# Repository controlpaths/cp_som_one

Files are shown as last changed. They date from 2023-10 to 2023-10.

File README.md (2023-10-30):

# CP SOM ONE

The CP SOM ONE is a Open Source System-On-Module that features an FPGA Artix7 from AMD. 

## Images

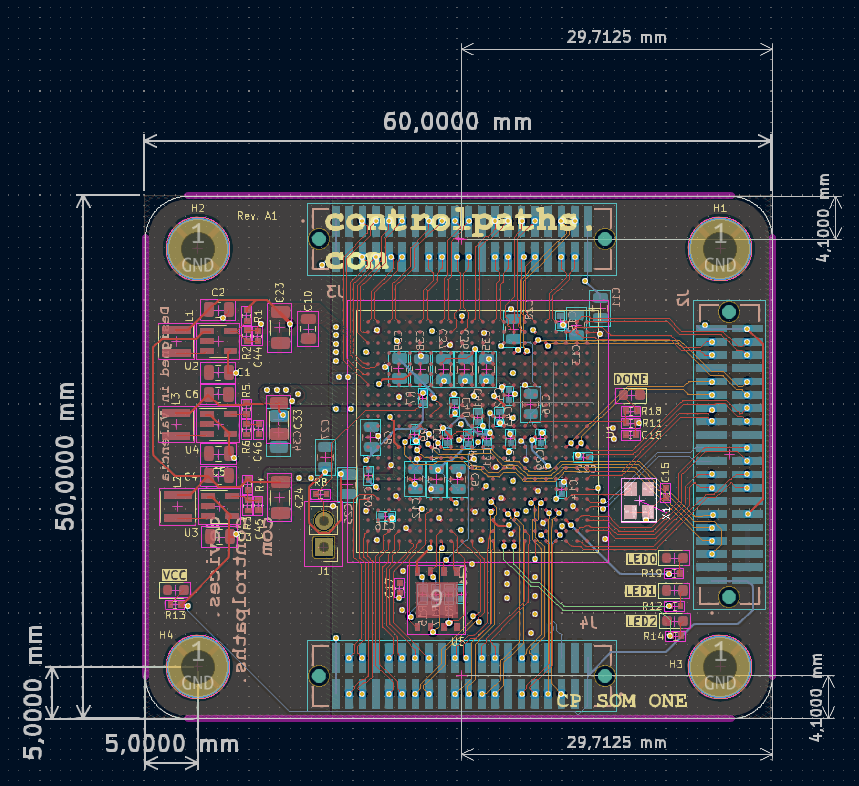
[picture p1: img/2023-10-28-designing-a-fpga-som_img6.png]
 

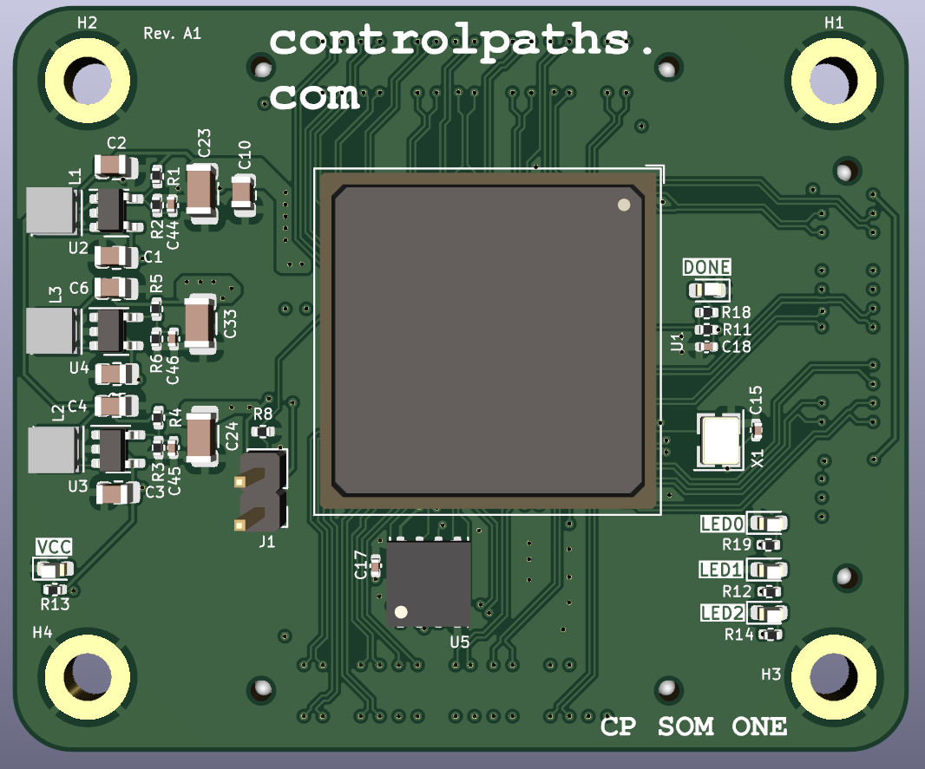
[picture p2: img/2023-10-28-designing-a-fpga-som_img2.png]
 

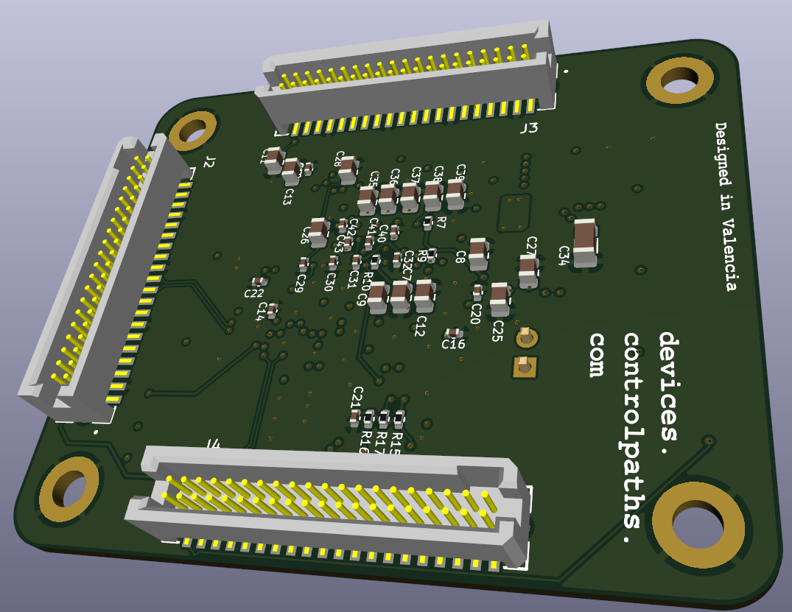
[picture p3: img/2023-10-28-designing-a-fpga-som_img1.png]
 

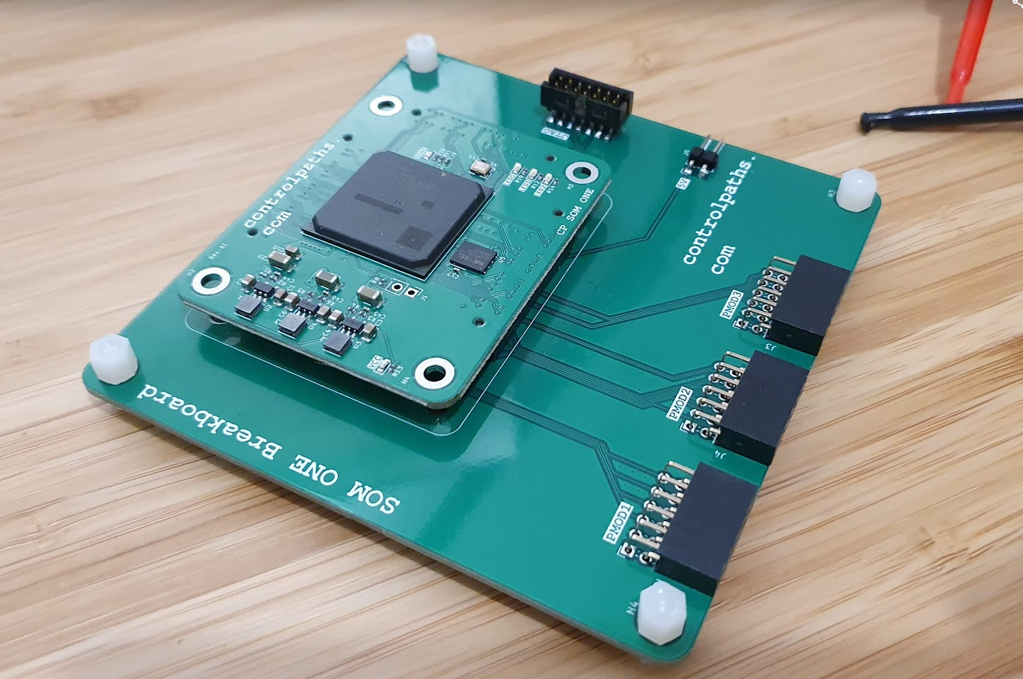
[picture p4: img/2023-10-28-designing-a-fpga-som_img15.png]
 

**More information in [controlpaths.com](https://www.controlpaths.com/2023/10/28/designing-a-fpga-som/)**

## Get yours

The CP SOM ONE is open source and all the files are shared. If you want to build your own, you can to go to the [JLCPCB](https://jlcpcb.com/?from=controlpaths) website, click on Order Now, and upload a zip file with all the fabrication files.

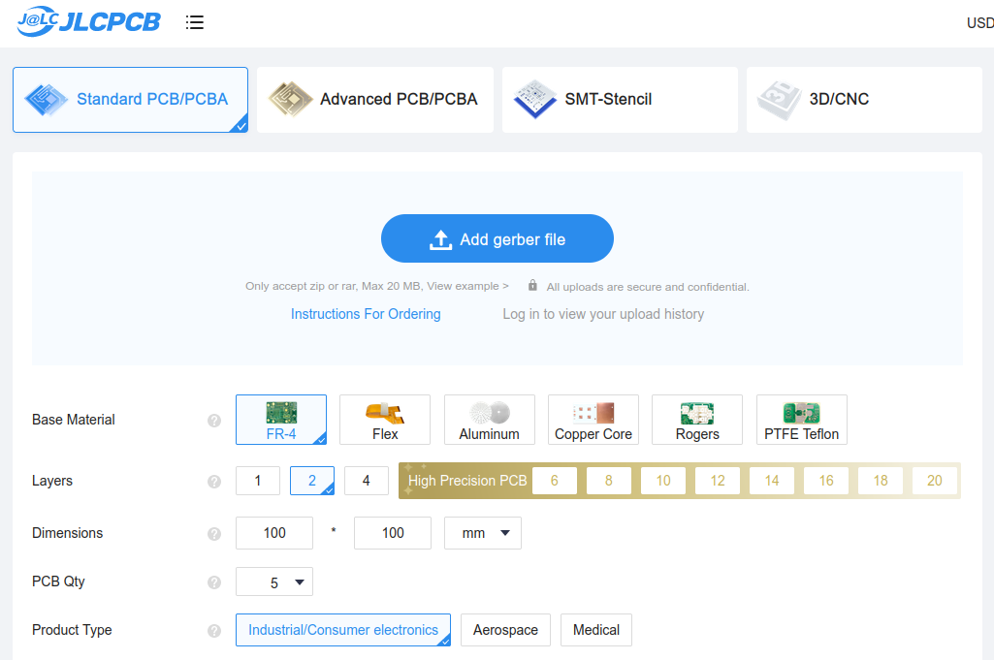
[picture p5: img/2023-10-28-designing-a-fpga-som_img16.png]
 

Then, you have to configure some aspects of the board. For this SOM, I just changed the Surface Finish to LeadFree HASL. Also, you can customize the color of your board.

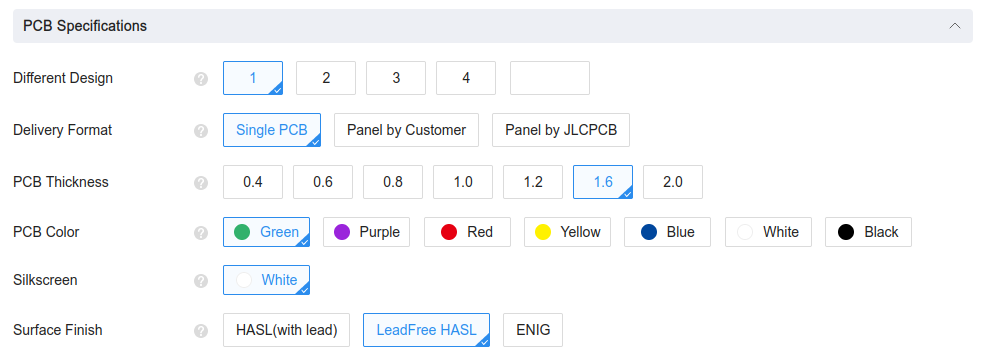
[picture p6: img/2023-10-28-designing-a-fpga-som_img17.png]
 

When the PCB service options are ready, then you have to select the PCB Assembly process. here we have to set whether the components are on one or both sides of the board, and the quantity we need. 

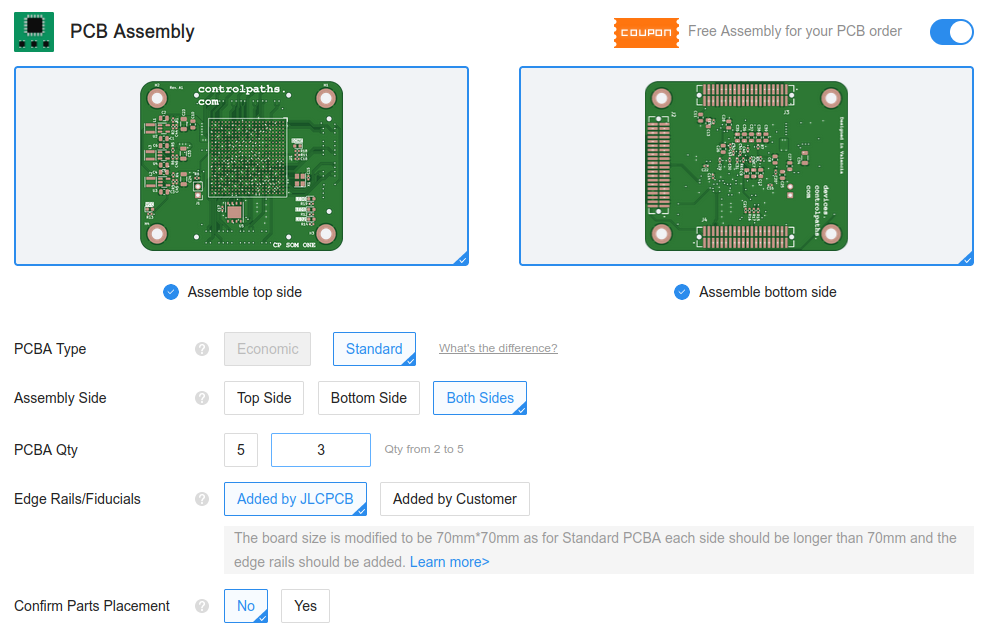
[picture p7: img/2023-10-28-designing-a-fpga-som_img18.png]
 

Then, when we confirm the board, the web application will ask us for two files, the position file for the components, and the bill of materials. Both files are generated in KiCad and are available in the GitHub repository.

Finally, you have to complete the order and two weeks later, the board will be in your house.

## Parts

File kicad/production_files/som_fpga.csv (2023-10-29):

# | Reference | Qty | Value | Footprint | DNP | JLCPCB
1 | C1, C3, C5, C7, C8, C9, C10, C11, C12, C13, C25, C26, C27, C28, C35, C36, C37, C38, C39 | 19 | 4u7 | Capacitor_SMD:C_0805_2012Metric |  | C162420
2 | C2, C4, C6 | 3 | 10u | Capacitor_SMD:C_0805_2012Metric |  | C105505
3 | C14, C15, C16, C17, C18, C19, C20, C21, C22, C29, C30, C31, C32, C40, C41, C42, C43, C44, C45, C46 | 20 | 0.47u | Capacitor_SMD:C_0402_1005Metric |  | C106255
4 | C23, C24 | 2 | 47u | Capacitor_SMD:C_1206_3216Metric |  | C385907
5 | C33, C34 | 2 | 100u | Capacitor_SMD:C_1206_3216Metric |  | C268006
6 | D1 | 1 | DONE | LED_SMD:LED_0603_1608Metric |  | C89814
7 | D2 | 1 | VCC | LED_SMD:LED_0603_1608Metric |  | C601673
8 | D3, D4, D5 | 3 | USER_LED | LED_SMD:LED_0603_1608Metric |  | C40378
9 | L1, L2, L3 | 3 | 2u2 | inductors:IND_LQH3NPN2R2MJRL |  | C341775
10 | R1 | 1 | 100k | Resistor_SMD:R_0402_1005Metric |  | C131362
11 | R2, R5 | 2 | 22k | Resistor_SMD:R_0402_1005Metric |  | C409681
12 | R3 | 1 | 120k | Resistor_SMD:R_0402_1005Metric |  | C323683
13 | R4 | 1 | 240k | Resistor_SMD:R_0402_1005Metric |  | C323663
14 | R6 | 1 | 33k | Resistor_SMD:R_0402_1005Metric |  | C416388
15 | R7, R8, R9, R10, R15, R16, R17 | 7 | 4k7 | Resistor_SMD:R_0402_1005Metric |  | C3017492
16 | R11 | 1 | 330 | Resistor_SMD:R_0402_1005Metric |  | C881192
17 | R12, R13, R14, R19 | 4 | 10k | Resistor_SMD:R_0402_1005Metric |  | C328298
18 | R18 | 1 | 100 | Resistor_SMD:R_0402_1005Metric |  | C471762
19 | U1 | 1 | XC7A75T-FGG484 | Package_BGA:FB-BGA-484_23.0x23.0mm_Layout22x22_P1.0mm |  | C396343
20 | U2 | 1 | TLV62565DBVR | Package_TO_SOT_SMD:SOT-23-5 |  | C87122
21 | U3, U4 | 2 | TLV62565DBVR | Package_TO_SOT_SMD:SOT-23-5 |  | C23902
22 | U5 | 1 | MX25L12833F | Package_SON:WSON-8-1EP_6x5mm_P1.27mm_EP3.4x4mm |  | C2802709
23 | X1 | 1 | SG-8018CE | Crystal:Crystal_SMD_3225-4Pin_3.2x2.5mm |  | C390488

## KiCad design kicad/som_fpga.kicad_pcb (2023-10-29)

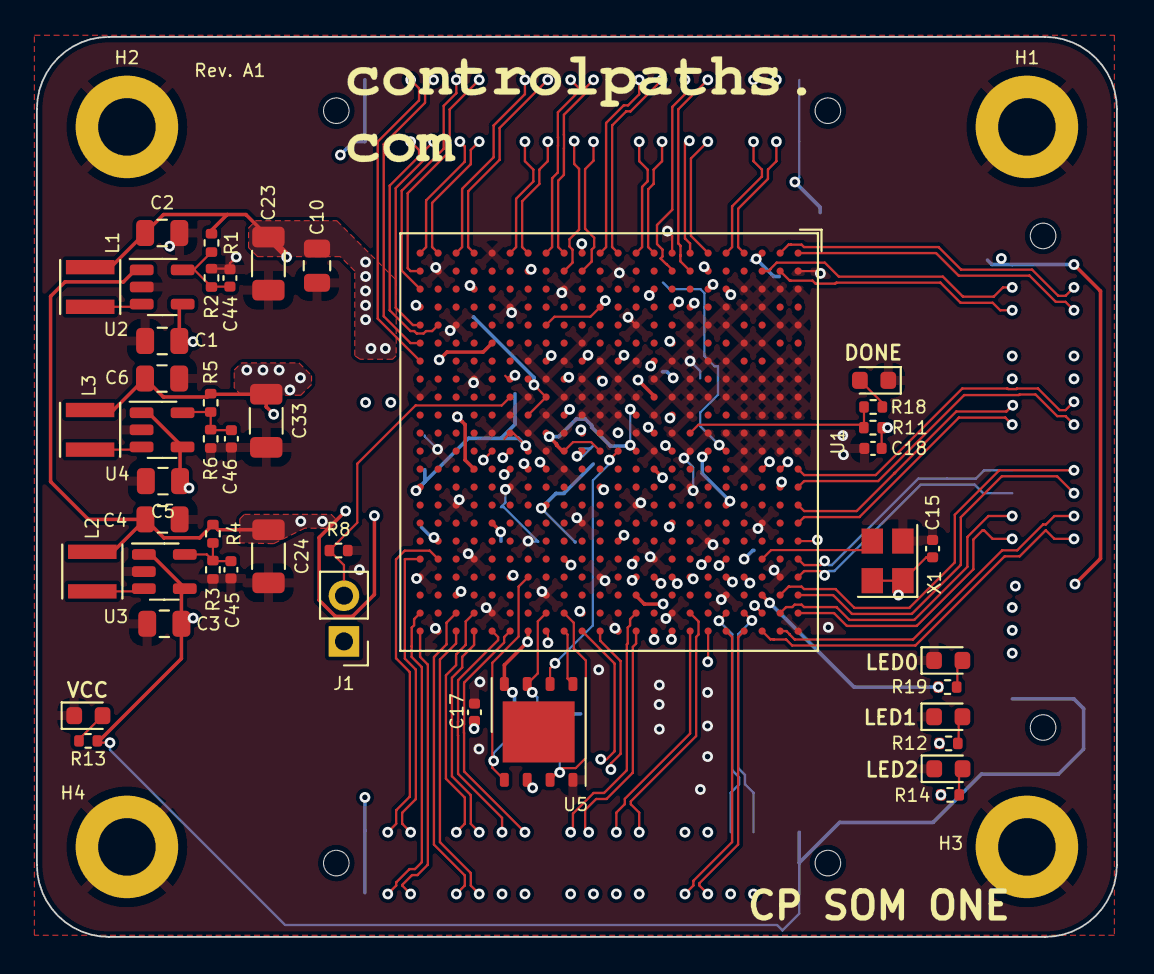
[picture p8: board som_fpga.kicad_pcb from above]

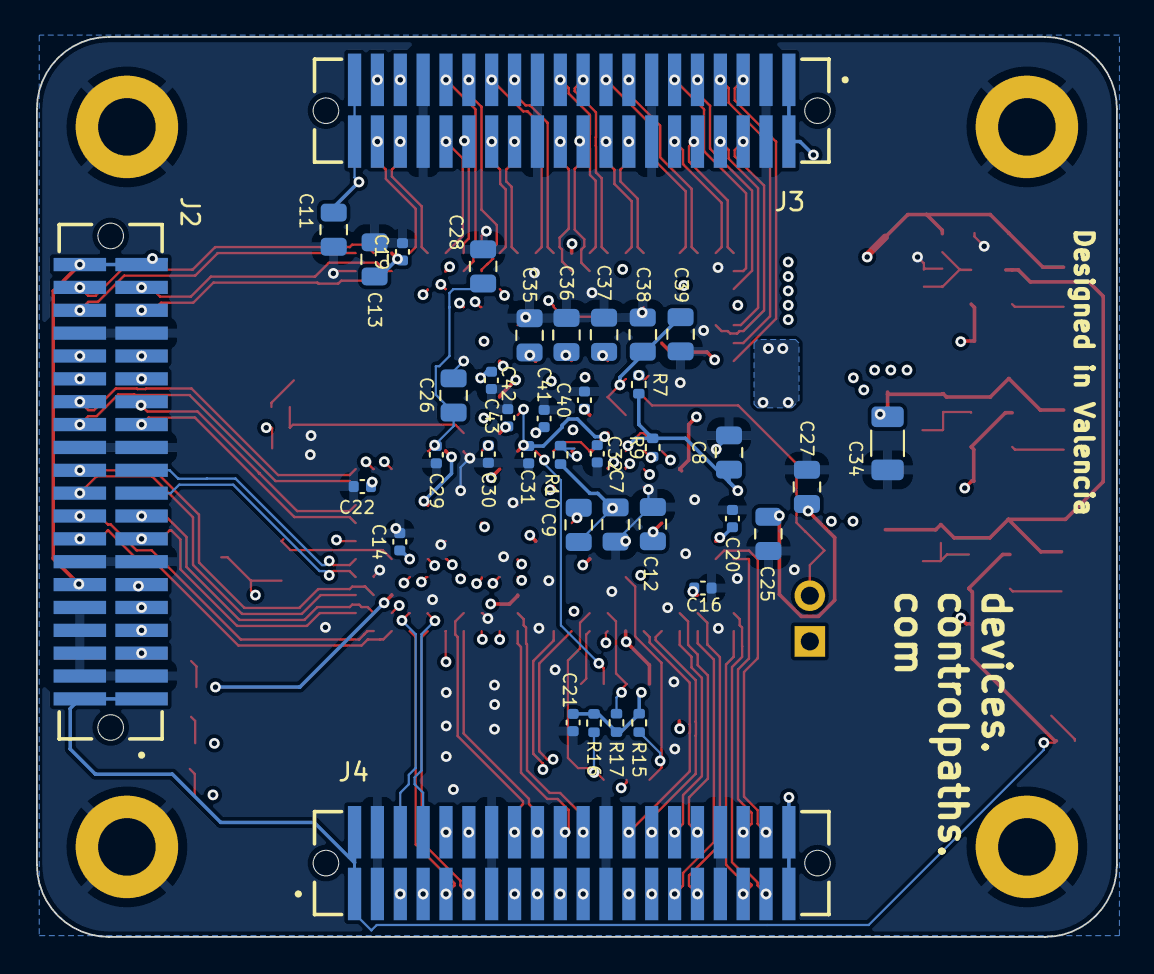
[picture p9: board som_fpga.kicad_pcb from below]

Board: 4 copper layers, 60.0 x 50.0 mm, 88 parts (39 on the bottom side), 111 nets.

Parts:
C1, C3, C5, C7, C8, C9, C10, C11, C12, C13, C25, C26, C27, C28, C35, C36, C37, C38, C39: 4u7; C_0805_2012Metric
C2, C4, C6: 10u; C_0805_2012Metric
C14, C15, C16, C17, C18, C19, C20, C21, C22, C29, C30, C31, C32, C40, C41, C42, C43, C44, C45, C46: 0.47u; C_0402_1005Metric
C23, C24: 47u; C_1206_3216Metric
C33, C34: 100u; C_1206_3216Metric
D1: DONE; LED_0603_1608Metric
D2: VCC; LED_0603_1608Metric
D3, D4, D5: USER_LED; LED_0603_1608Metric
H1, H2, H3, H4: MountingHole_Pad; MountingHole_3.2mm_M3_ISO7380_Pad
J1: Conn_01x02_Pin; PinHeader_1x02_P2.54mm_Vertical
J2, J3, J4: Conn_02x20_Odd_Even; SAMTEC_TFM-120-02-S-D-A
L1, L2, L3: 2u2; IND_LQH3NPN2R2MJRL
R1: 100k; R_0402_1005Metric
R2, R5: 22k; R_0402_1005Metric
R3: 120k; R_0402_1005Metric
R4: 240k; R_0402_1005Metric
R6: 33k; R_0402_1005Metric
R7, R8, R9, R10, R15, R16, R17: 4k7; R_0402_1005Metric
R11: 330; R_0402_1005Metric
R12, R13, R14, R19: 10k; R_0402_1005Metric
R18: 100; R_0402_1005Metric
U1: XC7A35T-FGG484; FB-BGA-484_23.0x23.0mm_Layout22x22_P1.0mm
U2, U3, U4: TLV62565DBVR; SOT-23-5
U5: MX25L12833F; WSON-8-1EP_6x5mm_P1.27mm_EP3.4x4mm
U6: cp_logo25mm; logo25mm
X1: SG-8018CE; Crystal_SMD_3225-4Pin_3.2x2.5mm

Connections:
+1V0: C6.1, C33.1, C34.1, C35.1, C36.1, C37.1, C38.1, C39.1, C40.1, C41.1, C42.1, C43.1, L3.2, R5.1, U1.H8 (VCCINT), U1.H10 (VCCINT), U1.J7 (VCCINT), U1.J9 (VCCINT), U1.J11 (VCCBRAM), U1.K8 (VCCINT), U1.L7 (VCCINT), U1.L11 (VCCBRAM), U1.M8 (VCCINT), U1.N7 (VCCINT), U1.N11 (VCCBRAM), U1.P8 (VCCINT), U1.P10 (VCCINT), U1.R7 (VCCINT), U1.R9 (VCCINT), U1.T8 (VCCINT), U1.T10 (VCCINT)
+1V8: C4.1, C24.1, C25.1, C26.1, C27.1, C28.1, C29.1, C30.1, C31.1, C32.1, L2.2, R4.1, U1.E12 (VCCBATT_0), U1.H12 (VCCAUX), U1.K10 (VCCADC_0), U1.K12 (VCCAUX), U1.M12 (VCCAUX), U1.P12 (VCCAUX), U1.R11 (VCCAUX), U2.1 (EN)
+3V3: C2.1, C7.1, C8.1, C9.1, C10.1, C11.1, C12.1, C13.1, C14.1, C15.1, C16.1, C17.1, C18.1, C19.1, C20.1, C21.1, C22.1, C23.1, J1.1, J2.12, J2.39, J2.40, J3.39, J3.40, J4.39, J4.40, L1.2, R1.1, R7.2, R9.2, R10.2, R11.2, R15.1, R16.1, R17.1, U1.A17 (VCCO_16), U1.AA7 (VCCO_34), U1.AA17 (VCCO_13), U1.AB4 (VCCO_34), U1.AB14 (VCCO_13), U1.B14 (VCCO_16), U1.C1 (VCCO_35), U1.C21 (VCCO_16), U1.D18 (VCCO_16), U1.E15 (VCCO_16), U1.F2 (VCCO_35), U1.F12 (VCCO_0), U1.F22 (VCCO_16), U1.G19 (VCCO_15), U1.H6 (VCCO_35), U1.H16 (VCCO_15), U1.J3 (VCCO_35), U1.J13 (VCCO_15), U1.K20 (VCCO_15), U1.L17 (VCCO_15), U1.M4 (VCCO_35), U1.M14 (VCCO_14), U1.N1 (VCCO_35), U1.N21 (VCCO_15), U1.P18 (VCCO_14), U1.R5 (VCCO_34), U1.R15 (VCCO_14), U1.T2 (VCCO_34), U1.T12 (VCCO_0), U1.T22 (VCCO_14), U1.U11 (M0_0), U1.U19 (VCCO_14), U1.V6 (VCCO_34), U1.V16 (VCCO_13), U1.W3 (VCCO_34), U1.W13 (VCCO_13), U1.Y10 (VCCO_13), U1.Y20 (VCCO_14), U5.8 (VCC), X1.1 (OE), X1.4 (Vcc)
+5V: C1.1, C3.1, C5.1, J2.1, J2.2, J3.1, J3.2, J4.1, J4.2, R13.1, U2.4 (VIN), U3.1 (EN), U3.4 (VIN), U4.1 (EN), U4.4 (VIN)
/FPGA_bank13_14/FLASH_CS: R15.2, U1.T19 (IO_L6P_T0_FCS_B_14), U5.1 (~CS)
/FPGA_bank13_14/FLASH_D0: U1.P22 (IO_L1P_T0_D00_MOSI_14), U5.5 (SI/SIO0)
/FPGA_bank13_14/FLASH_D1: U1.R22 (IO_L1N_T0_D01_DIN_14), U5.2 (SO/SIO1)
/FPGA_bank13_14/FLASH_D2: R16.2, U1.P21 (IO_L2P_T0_D02_14), U5.3 (~WP/SIO2)
/FPGA_bank13_14/FLASH_D3: R17.2, U1.R21 (IO_L2N_T0_D03_14), U5.7 (~RESET/SIO3)
CONN1.1_N: J3.7, U1.AB6 (IO_L20N_T3_34)
CONN1.1_P: J3.5, U1.AB7 (IO_L20P_T3_34)
CONN1.2_N: J3.8, U1.AB5 (IO_L10N_T1_34)
CONN1.2_P: J3.6, U1.AA5 (IO_L10P_T1_34)
CONN1.3_N: J3.11, U1.AB2 (IO_L8N_T1_34)
CONN1.3_P: J3.9, U1.AB3 (IO_L8P_T1_34)
CONN1.4_N: J3.10, U1.AB1 (IO_L7N_T1_34)
CONN1.4_P: J3.12, U1.AA1 (IO_L7P_T1_34)
CONN1.5_N: J3.15, U1.Y1 (IO_L5N_T0_34)
CONN1.5_P: J3.17, U1.W1 (IO_L5P_T0_34)
CONN1.6_N: J3.16, U1.U1 (IO_L1N_T0_34)
CONN1.6_P: J3.18, U1.T1 (IO_L1P_T0_34)
CONN1.7_N: J3.21, U1.P1 (IO_L20N_T3_35)
CONN1.7_P: J3.19, U1.R1 (IO_L20P_T3_35)
CONN1.8_N: J3.22, U1.N2 (IO_L22N_T3_35)
CONN1.8_P: J3.20, U1.P2 (IO_L22P_T3_35)
CONN1.9_N: J3.27, U1.L1 (IO_L15N_T2_DQS_35)
CONN1.9_P: J3.25, U1.M1 (IO_L15P_T2_DQS_35)
CONN1.10_N: J3.28, U1.J1 (IO_L7N_T1_AD6N_35)
CONN1.10_P: J3.26, U1.K1 (IO_L7P_T1_AD6P_35)
CONN1.11_N: J3.31, U1.G2 (IO_L8N_T1_AD14N_35)
CONN1.11_P: J3.29, U1.H2 (IO_L8P_T1_AD14P_35)
CONN1.12_N: J3.32, U1.F1 (IO_L5N_T0_AD13N_35)
CONN1.12_P: J3.30, U1.G1 (IO_L5P_T0_AD13P_35)
CONN1.13_N: J3.37, U1.G4 (IO_L12N_T1_MRCC_35)
CONN1.13_P: J3.35, U1.H4 (IO_L12P_T1_MRCC_35)
CONN1.14_N: J3.38, U1.D1 (IO_L3N_T0_DQS_AD5N_35)
CONN1.14_P: J3.36, U1.E1 (IO_L3P_T0_DQS_AD5P_35)
CONN2.1_N: J4.5, U1.D19 (IO_L14N_T2_SRCC_16)
CONN2.1_P: J4.7, U1.E19 (IO_L14P_T2_SRCC_16)
CONN2.2_N: J4.6, U1.D21 (IO_L23N_T3_16)
CONN2.2_P: J4.8, U1.E21 (IO_L23P_T3_16)
CONN2.3_N: J4.9, U1.D22 (IO_L22N_T3_16)
CONN2.3_P: J4.11, U1.E22 (IO_L22P_T3_16)
CONN2.4_N: J4.10, U1.E18 (IO_L15N_T2_DQS_16)
CONN2.4_P: J4.12, U1.F18 (IO_L15P_T2_DQS_16)
CONN2.5_N: J4.15, U1.H19 (IO_L12N_T1_MRCC_15)
CONN2.5_P: J4.17, U1.J19 (IO_L12P_T1_MRCC_15)
CONN2.6_N: J4.18, U1.G22 (IO_L24N_T3_16)
CONN2.6_P: J4.16, U1.G21 (IO_L24P_T3_16)
CONN2.7_N: J4.21, U1.K19 (IO_L13N_T2_MRCC_15)
CONN2.7_P: J4.19, U1.K18 (IO_L13P_T2_MRCC_15)
CONN2.8_N: J4.20, U1.K22 (IO_L9N_T1_DQS_AD3N_15)
CONN2.8_P: J4.22, U1.K21 (IO_L9P_T1_DQS_AD3P_15)
CONN2.9_N: J4.25, U1.M22 (IO_L15N_T2_DQS_ADV_B_15)
CONN2.9_P: J4.27, U1.N22 (IO_L15P_T2_DQS_15)
CONN2.10_N: J4.28, U1.V22 (IO_L3N_T0_DQS_EMCCLK_14)
CONN2.10_P: J4.26, U1.U22 (IO_L3P_T0_DQS_PUDC_B_14)
CONN2.11_N: J4.29, U1.Y22 (IO_L9N_T1_DQS_D13_14)
CONN2.11_P: J4.31, U1.Y21 (IO_L9P_T1_DQS_14)
CONN2.12_N: J4.30, U1.W22 (IO_L7N_T1_D10_14)
CONN2.12_P: J4.32, U1.W21 (IO_L7P_T1_D09_14)
CONN2.13_N: J4.35, U1.AB22 (IO_L10N_T1_D15_14)
CONN2.13_P: J4.37, U1.AB21 (IO_L10P_T1_D14_14)
CONN2.14_N: J4.36, U1.AB18 (IO_L17N_T2_A13_D29_14)
CONN2.14_P: J4.38, U1.AA18 (IO_L17P_T2_A14_D30_14)
CONN3.5_N: J2.15, U1.A21 (IO_L21N_T3_DQS_16)
CONN3.5_P: J2.17, U1.B21 (IO_L21P_T3_DQS_16)
CONN3.6_N: J2.18, U1.B22 (IO_L20N_T3_16)
CONN3.6_P: J2.16, U1.C22 (IO_L20P_T3_16)
CONN3.7_N: J2.19, U1.A19 (IO_L17N_T2_16)
CONN3.7_P: J2.21, U1.A18 (IO_L17P_T2_16)
CONN3.8_N: J2.20, U1.A20 (IO_L16N_T2_16)
CONN3.8_P: J2.22, U1.B20 (IO_L16P_T2_16)
CONN3.9_N: J2.25, U1.A16 (IO_L9N_T1_DQS_16)
CONN3.9_P: J2.27, U1.A15 (IO_L9P_T1_DQS_16)
CONN3.10_N: J2.26, U1.A14 (IO_L10N_T1_16)
CONN3.10_P: J2.28, U1.A13 (IO_L10P_T1_16)
CONN3.11_N: J2.29, U1.B13 (IO_L8N_T1_16)
CONN3.11_P: J2.31, U1.C13 (IO_L8P_T1_16)
CONN3.12_N: J2.30, U1.E3 (IO_L6N_T0_VREF_35)
CONN3.12_P: J2.32, U1.F3 (IO_L6P_T0_35)
CONN3.13_N: J2.35, U1.B2 (IO_L2N_T0_AD12N_35)
CONN3.13_P: J2.37, U1.C2 (IO_L2P_T0_AD12P_35)
CONN3.14_N: J2.36, U1.A1 (IO_L1N_T0_AD4N_35)
CONN3.14_P: J2.38, U1.B1 (IO_L1P_T0_AD4P_35)
FLASH_SCLK: U1.L12 (CCLK_0), U5.6 (SCLK)
GND: C1.2, C2.2, C3.2, C4.2, C5.2, C6.2, C7.2, C8.2, C9.2, C10.2, C11.2, C12.2, C13.2, C14.2, C15.2, C16.2, C17.2, C18.2, C19.2, C20.2, C21.2, C22.2, C23.2, C24.2, C25.2, C26.2, C27.2, C28.2, C29.2, C30.2, C31.2, C32.2, C33.2, C34.2, C35.2, C36.2, C37.2, C38.2, C39.2, C40.2, C41.2, C42.2, C43.2, C44.2, C45.2, C46.2, D1.1 (K), D2.1 (K), D3.1 (K), D4.1 (K), D5.1 (K), H1.1, H2.1, H3.1, H4.1, J2.3, J2.4, J2.6, J2.8, J2.10, J2.13, J2.14, J2.23, J2.24, J2.33, J2.34, J3.3, J3.4, J3.13, J3.14, J3.23, J3.24, J3.33, J3.34, J4.3, J4.4, J4.13, J4.14, J4.23, J4.24, J4.33, J4.34, R2.2, R3.2, R6.2, R8.2, U1.A2 (GND), U1.A3 (GND), U1.A5 (GND), U1.A7 (GND), U1.A8 (MGTPRXN0_216), U1.A9 (GND), U1.A10 (MGTPRXN2_216), U1.A11 (GND), U1.A12 (GND), U1.A22 (GND), U1.AA2 (GND), U1.AA12 (GND), U1.AA22 (GND), U1.AB9 (GND), U1.AB19 (GND), U1.B3 (GND), U1.B5 (MGTAVTT), U1.B7 (MGTAVTT), U1.B8 (MGTPRXP0_216), U1.B9 (MGTAVTT), U1.B10 (MGTPRXP2_216), U1.B11 (MGTAVTT), U1.B12 (GND), U1.B19 (GND), U1.C3 (GND), U1.C4 (MGTAVTT), U1.C6 (GND), U1.C8 (MGTAVTT), U1.C9 (MGTPRXN3_216), U1.C10 (GND), U1.C11 (MGTPRXN1_216), U1.C12 (GND), U1.C16 (GND), U1.D3 (GND), U1.D4 (GND), U1.D6 (MGTAVCC), U1.D8 (GND), U1.D9 (MGTPRXP3_216), U1.D10 (MGTAVCC), U1.D11 (MGTPRXP1_216), U1.D12 (GND), U1.D13 (GND), U1.E4 (GND), U1.E5 (GND), U1.E7 (GND), U1.E8 (MGTAVCC), U1.E9 (GND), U1.E11 (GND), U1.E20 (GND), U1.F5 (GND), U1.F7 (MGTAVCC), U1.F9 (MGTAVCC), U1.F11 (GND), U1.F17 (GND), U1.G5 (GND), U1.G6 (GND), U1.G7 (GND), U1.G8 (GND), U1.G9 (GND), U1.G10 (GND), U1.G12 (GND), U1.G14 (GND), U1.H1 (GND), U1.H7 (GND), U1.H9 (GND), U1.H11 (GND), U1.H21 (GND), U1.J8 (GND), U1.J10 (GND), U1.J12 (GND), U1.J18 (GND), U1.K5 (GND), U1.K7 (GND), U1.K9 (GNDADC_0), U1.K11 (GND), U1.K15 (GND), U1.L2 (GND), U1.L8 (GND), U1.L9 (VREFN_0), U1.L10 (VP_0), U1.L22 (GND), U1.M7 (GND), U1.M9 (VN_0), U1.M10 (VREFP_0), U1.M11 (GND), U1.M19 (GND), U1.N6 (GND), U1.N8 (GND), U1.N9 (DXN_0), U1.N10 (DXP_0), U1.N16 (GND), U1.P3 (GND), U1.P7 (GND), U1.P9 (GND), U1.P11 (GND), U1.P13 (GND), U1.R8 (GND), U1.R10 (GND), U1.R12 (GND), U1.R20 (GND), U1.T7 (GND), U1.T9 (GND), U1.T11 (GND), U1.T17 (GND), U1.U4 (GND), U1.U10 (M1_0), U1.U14 (GND), U1.V1 (GND), U1.V11 (GND), U1.V21 (GND), U1.W8 (GND), U1.W18 (GND), U1.Y5 (GND), U1.Y15 (GND), U2.2 (GND), U3.2 (GND), U4.2 (GND), U5.4 (GND), X1.2 (GND)
JTAG_TCK: J2.7, U1.V12 (TCK_0)
JTAG_TDI: J2.11, U1.R13 (TDI_0)
JTAG_TDO: J2.9, U1.U13 (TDO_0)
JTAG_TMS: J2.5, U1.T13 (TMS_0)
unnamed: D1.2 (A), R18.1
unnamed: D2.2 (A), R13.2
unnamed: D3.2 (A), R12.2
unnamed: D4.2 (A), R14.2
unnamed: D5.2 (A), R19.2
unnamed: J1.2, R8.1, U1.U9 (M2_0)
unnamed: U1.C18 (IO_L13P_T2_MRCC_16), X1.3 (OUT)
unnamed: R7.1, U1.U8 (CFGBVS_0)
unnamed: R11.1, R18.2, U1.G11 (DONE_0)
unnamed: R9.1, U1.U12 (INIT_B_0)
unnamed: R10.1, U1.N12 (PROGRAM_B_0)
unnamed: C44.1, R1.2, R2.1, U2.5 (FB)
unnamed: L1.1, U2.3 (SW)
unnamed: C45.1, R3.1, R4.2, U3.5 (FB)
unnamed: L2.1, U3.3 (SW)
unnamed: C46.1, R5.2, R6.1, U4.5 (FB)
unnamed: L3.1, U4.3 (SW)
USER_LED0: R19.1, U1.C20 (IO_L19N_T3_VREF_16)
USER_LED1: R12.1, U1.H22 (IO_L7N_T1_AD2N_15)
USER_LED2: R14.1, U1.J22 (IO_L7P_T1_AD2P_15)

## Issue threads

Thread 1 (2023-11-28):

PCB lacks layers in KiCad 7.0

alextousss, 2023-11-28:
Hi,

First of all, thank you for making this! I'm a beginner in FPGA implementation and this design really helps me
I tried opening it in Kicad 7.0, and I'm having a problem: I can't see the traces on the board and the nets seem not to be linked. See attached picture.

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

Also, you wrote on your blog that this was a six-layer board, but when I look into the project's board setup, there are only four of them.
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

Could you please help me on this ?
Thank you again for your work,

Alex

controlpaths, 2024-01-02:
Hi,
seems you have some configuration to hide routes and vias... Is this happening in all layers? in the PCBnew window, on the right side you can configure what you see. Also, if you press 'B' all the zones will be reloaded. If the gaps for the traces are still in the zones, than the traces exists, but they are hidden.
Thanks!

alextousss, 2024-01-02:
Hi, thanks for helping me. The issue was trivial and I was too embarrassed to close it ...

I've now changed most of the things on the board although I'm still using your design for power supplies. Could you please clarify on which terms your work could be used ?

Also, is there a specific reason for using a regular 30mhz quartz instead of a 100mhz VCXO oscillator found on other boards ?

Thanks!
Alex

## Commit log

2023-10-29 First version
    [FPGA_bank0_vss.kicad_sch, FPGA_bank13_14.kicad_sch, FPGA_bank15_16.kicad_sch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]
2023-11-02 Supply fb resistor marked as Not Populated
    [supply.kicad_sch]
